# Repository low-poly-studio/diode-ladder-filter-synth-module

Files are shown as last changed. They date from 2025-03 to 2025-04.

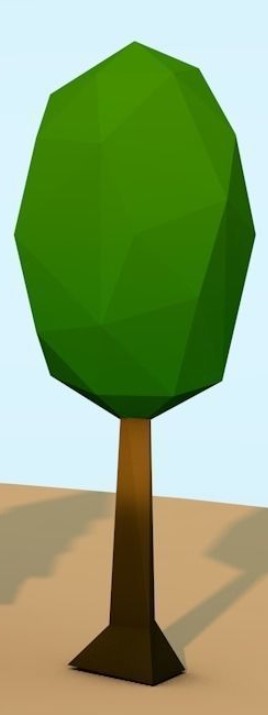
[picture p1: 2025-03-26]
artwork/low-poly-tree-4.jpg

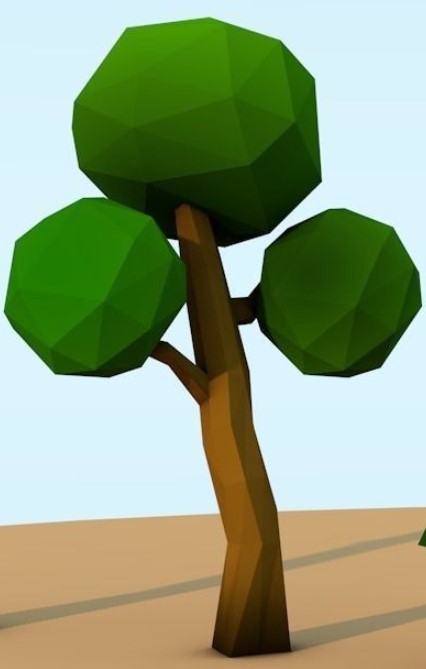
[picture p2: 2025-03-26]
artwork/low-poly-tree-3.jpg

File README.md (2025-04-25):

# diode-ladder-filter-synth-module
 Diode Ladder Filter Synth Module

 Putting this here as I dont have a better place for it at the moment

BL-HUF35A-AV-TRB - Red
TJ-S2012SW8TGLC0A-A5 - orange
BL-HJC36G-AV-TRB - amber
KT-0805Y - yellow, basic
KT-0805YG - yellow green
APT2012CGCK  - green
KT-0805G - emerald
LTST-C170TBKT - blue
E6C0805TKAY1UDA - foggy yellow lense ice blue
GZ2012D101TF - purple
XL-2012UPC - pink
KT-0805W - white

## JLC LED Library
| Colour 	| MF part 		 |  JLC part| Basic? |
|---		 |---			 |---		 |--- |
|red		 |BL-HUF35A-AV-TRB	|		 | |
|orange-red		|ORH-R35A	|	C205444	||
|Orange		|TJ-S2012SW8TGLC0A-A5	|		||
|Amber		|BL-HJC36G-AV-TRB	|	0605!	||
|Yellow		|KT-0805Y		||
|yellow-green	|KT-0805YG	|	|		|
|green		|APT2012CGCK		|	||
|emerald	|KT-0805G		||
|blue		|LTST-C170TBKT	|	|	|
|ice-blue	|E6C0805TKAY1UDA	||		|
|purple		|GZ2012D101TF		|	||
|pink		|XL-2012UPC		|		|	|
|white		|KT-0805W		|	||

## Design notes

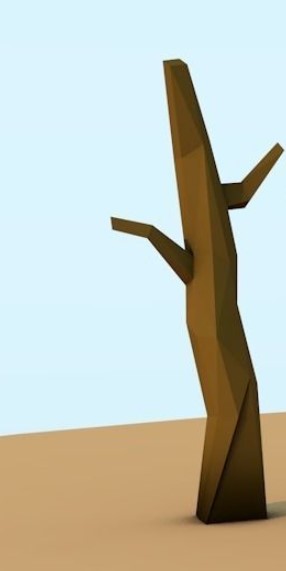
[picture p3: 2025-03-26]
artwork/low-poly-tree-2.jpg

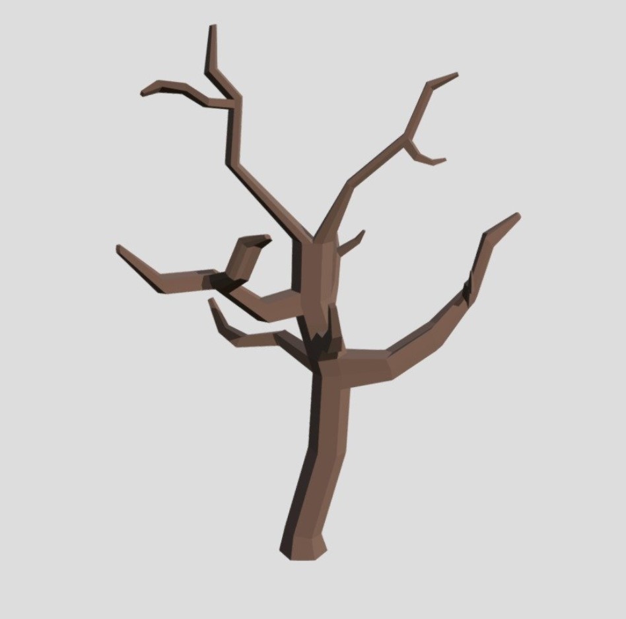
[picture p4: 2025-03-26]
artwork/low-poly-tree.jpg

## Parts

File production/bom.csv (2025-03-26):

Designator | Footprint | Quantity | Value | LCSC Part #
C1, C2, C3, C4, C5, C6, C7 | C_0805_2012_HandSolder_kawaii | 7 | 100n
C10, C11, C12, C13, C14 | 0805 | 5 | 1n
C8 | C_0805_2012_HandSolder_kawaii | 1 | 100p
C9 | 0805 | 1 | 1u
D1 | LED_0805_2012_Kawaii | 1 | V+
D10, D11, D12, D13, D14, D15, D7, D8, D9 | D_MiniMELF_kawaii | 9 | 1N4148
D16, D17 | LED_0805_2012_Kawaii | 2 | cv2
D2 | LED_0805_2012_Kawaii | 1 | V-
D3, D5 | LED_0805_2012_Kawaii | 2 | Audio Out
D4, D6 | LED_0805_2012_Kawaii | 2 | cv1
FB1, FB2 | 0805 | 2 | FerriteBead
J1 | synth-power-termbox-MPT-0,5-4-2.54_1x04_P2.54mm | 1 | power
J6 | synth-signal-MPT-1x10_P2.54mm_Horizontal_1 | 1 | synth-signal-header-10way
M1 | credit-card-screws | 1 | imogen-wren-card
PT1, PT2, PT3, PT4 | Potentiometer_Alpha-reversable | 4 | 100k
PT6, PT7 | Potentiometer_Bourns-reversable-1 | 2 | 100k-trim
R1, R2, R21, R24, R26, R27, R3, R4 | 0805 | 8 | 1k
R10 | 0805 | 1 | 2k
R11, R15, R23, R25, R5 | 0805 | 5 | 100k
R12 | 0805 | 1 | 14k
R13, R14 | 0805 | 2 | 68k
R16, R6 | 0805 | 2 | 27k
R17, R18, R19, R20, R22, R7, R8, R9 | 0805 | 8 | 33k
U1, U2 | SOIC-14_3.9x8.7mm_P1.27mm | 2 | TL074

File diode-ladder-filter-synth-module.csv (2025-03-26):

Id | Designator | Footprint | Quantity | Designation | Supplier and ref
1 | D14,D13,D15,D8,D10,D12,D7,D11,D9 | D_MiniMELF_kawaii | 9 | 1N4148
2 | R16,R6 | R_0805_2012Metric_Pad1.20x1.40mm_HandSolder | 2 | 27k
3 | C2,C4,C3,C1,C7,C5,C6 | C_0805_2012_HandSolder_kawaii | 7 | 100n
4 | D5,D3 | LED_0805_2012_Kawaii | 2 | Audio Out
5 | U2 | SOIC-14_3.9x8.7mm_P1.27mm | 1 | TL074
6 | R22,R7,R9,R19,R20,R18,R17,R8 | R_0805_2012Metric_Pad1.20x1.40mm_HandSolder | 8 | 33k
7 | J6 | synth-signal-MPT-1x10_P2.54mm_Horizontal_1 | 1 | synth-signal-header-10way
8 | PT1,PT3,PT4,PT2 | Potentiometer_Alpha-reversable | 4 | 100k
9 | C13,C14,C10,C11,C12 | C_0805_2012Metric_Pad1.18x1.45mm_HandSolder | 5 | 1n
10 | R26,R3,R1,R27,R4,R24,R21,R2 | R_0805_2012Metric_Pad1.20x1.40mm_HandSolder | 8 | 1k
11 | R23,R11,R15,R25,R5 | R_0805_2012Metric_Pad1.20x1.40mm_HandSolder | 5 | 100k
12 | D6,D4 | LED_0805_2012_Kawaii | 2 | cv1
13 | D2 | LED_0805_2012_Kawaii | 1 | V-
14 | C8 | C_0805_2012_HandSolder_kawaii | 1 | 100p
15 | R10 | R_0805_2012Metric_Pad1.20x1.40mm_HandSolder | 1 | 2k
16 | M1 | credit-card-screws | 1 | imogen-wren-card
17 | R13,R14 | R_0805_2012Metric_Pad1.20x1.40mm_HandSolder | 2 | 68k
18 | R12 | R_0805_2012Metric_Pad1.20x1.40mm_HandSolder | 1 | 14k
19 | J1 | synth-power-termbox-MPT-0,5-4-2.54_1x04_P2.54mm | 1 | power
20 | D17,D16 | LED_0805_2012_Kawaii | 2 | cv2
21 | PT7,PT6 | Potentiometer_Bourns-reversable-1 | 2 | 100k-trim
22 | FB1,FB2 | L_0805_2012Metric_Pad1.05x1.20mm_HandSolder | 2 | FerriteBead
23 | D1 | LED_0805_2012_Kawaii | 1 | V+
24 | U1 | SOIC-14_3.9x8.7mm_P1.27mm | 1 | TL074
25 | C9 | C_0805_2012Metric_Pad1.18x1.45mm_HandSolder | 1 | 1u

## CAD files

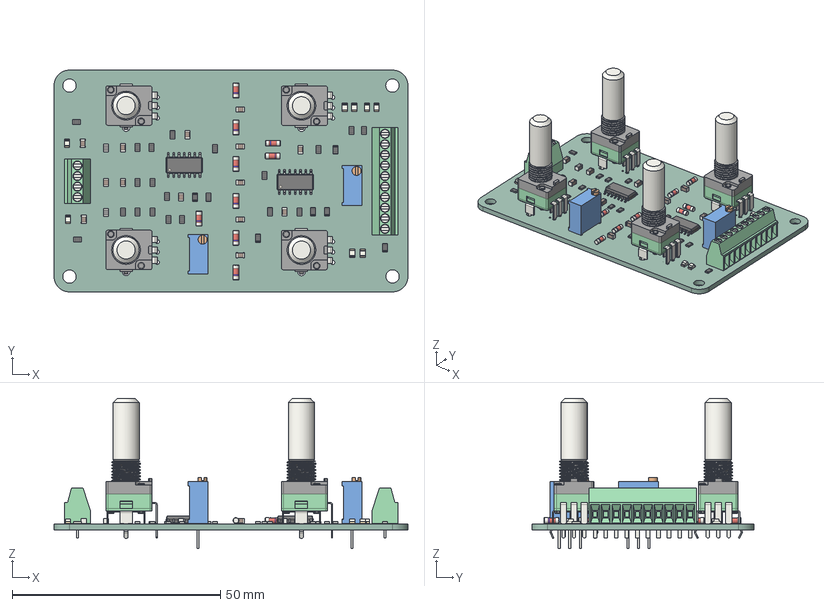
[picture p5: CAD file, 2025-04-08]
diode-ladder-filter-synth-module.step
85.1 x 53.3 x 36.1 mm
D_MiniMELF x 9
R_0805_2012Metric x 27
C_0805_2012Metric x 14
LED_0805_2012Metric x 8
SOIC-14_3.9x8.7mm_P1.27mm x 2
TerminalBlock_Phoenix_MPT-0,5-10-2.54_1x10_P2.54mm_Horizontal
ALPHA-RD901F-40 x 4
TerminalBlock_Phoenix_MPT-0,5-4-2.54_1x04_P2.54mm_Horizontal
Potentiometer_Bourns_3296W_Vertical x 2
L_0805_2012Metric x 2
diode-ladder-filter-synth-module_PCB

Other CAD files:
diode-ladder-filter-synth-module-CAD/ALPHA-RD901F-40.ipt
diode-ladder-filter-synth-module-CAD/C_0805_2012Metric.ipt
diode-ladder-filter-synth-module-CAD/D_MiniMELF.ipt
diode-ladder-filter-synth-module-CAD/LED_0805_2012Metric.ipt
diode-ladder-filter-synth-module-CAD/L_0805_2012Metric.ipt
diode-ladder-filter-synth-module-CAD/Potentiometer_Bourns_3296W_Vertical.ipt
diode-ladder-filter-synth-module-CAD/R_0805_2012Metric.ipt
diode-ladder-filter-synth-module-CAD/SOIC-14_3.9x8.7mm_P1.27mm.ipt
diode-ladder-filter-synth-module-CAD/TerminalBlock_Phoenix_MPT-0,5-10-2.54_1x10_P2.54mm_Horizontal.ipt
diode-ladder-filter-synth-module-CAD/TerminalBlock_Phoenix_MPT-0,5-4-2.54_1x04_P2.54mm_Horizontal.ipt
diode-ladder-filter-synth-module-CAD/diode-ladder-filter-synth-module.iam
diode-ladder-filter-synth-module-CAD/diode-ladder-filter-synth-module_PCB.ipt

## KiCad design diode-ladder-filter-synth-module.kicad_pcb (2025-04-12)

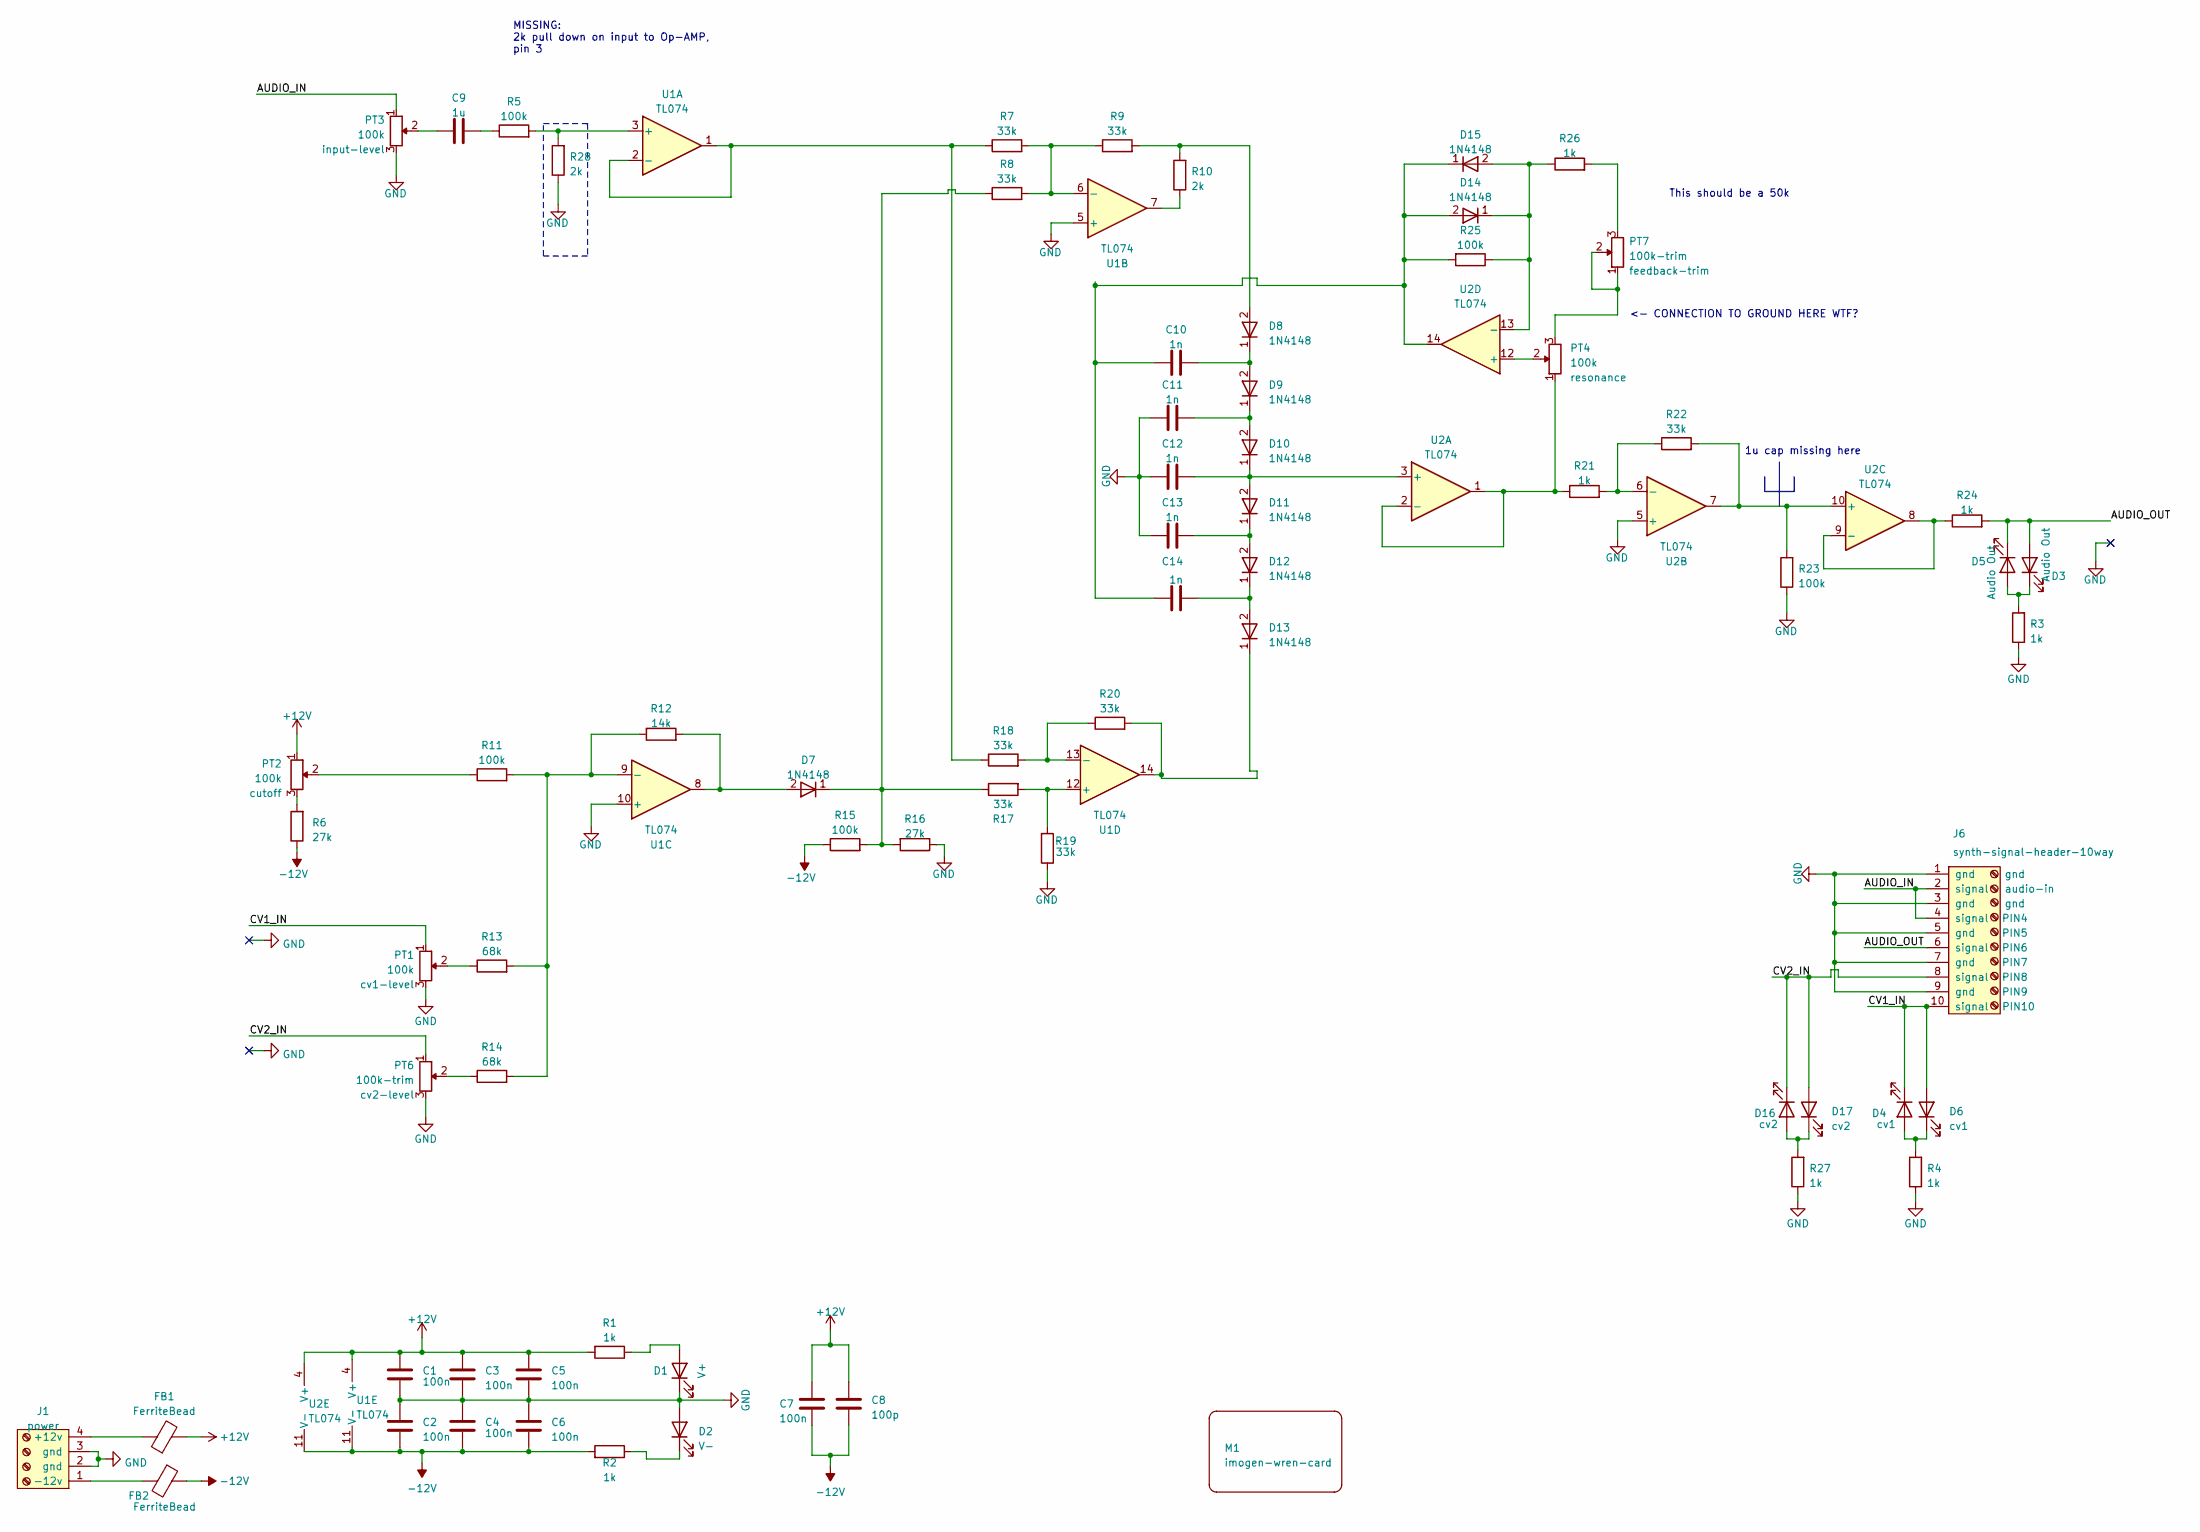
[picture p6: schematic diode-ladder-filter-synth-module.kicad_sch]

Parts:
C1, C2, C3, C4, C5, C6, C7: 100n; C_0805_2012_HandSolder_kawaii; JLCpart C779975
C8: 100p; C_0805_2012_HandSolder_kawaii; JLCpart C779975
C9: 1u; C_0805_2012Metric_Pad1.18x1.45mm_HandSolder
C10, C11, C12, C13, C14: 1n; C_0805_2012Metric_Pad1.18x1.45mm_HandSolder
D1: V+; LED_0805_2012_Kawaii; JLCpart C84259
D2: V-; LED_0805_2012_Kawaii; JLCpart C84259
D3, D5: Audio Out; LED_0805_2012_Kawaii; JLCpart C84259
D4, D6: cv1; LED_0805_2012_Kawaii; JLCpart C84259
D7, D8, D9, D10, D11, D12, D13, D14, D15: 1N4148; D_MiniMELF_kawaii
D16, D17: cv2; LED_0805_2012_Kawaii; JLCpart C84259
FB1, FB2: FerriteBead; L_0805_2012Metric_Pad1.05x1.20mm_HandSolder; JLCpart C845115
J1: power; synth-power-termbox-MPT-0,5-4-2.54_1x04_P2.54mm
J6: synth-signal-header-10way; synth-signal-MPT-1x10_P2.54mm_Horizontal_1
M1: imogen-wren-card; credit-card-screws
PT1, PT2, PT3, PT4: 100k; Potentiometer_Alpha-reversable
PT6, PT7: 100k-trim; Potentiometer_Bourns-reversable-1; JLCpart C118911
R1, R2, R3, R4, R21, R24, R26, R27: 1k; R_0805_2012Metric_Pad1.20x1.40mm_HandSolder; JLCpart C218388
R5, R11, R15, R23, R25: 100k; R_0805_2012Metric_Pad1.20x1.40mm_HandSolder; JLCpart C280020
R6, R16: 27k; R_0805_2012Metric_Pad1.20x1.40mm_HandSolder
R7, R8, R9, R17, R18, R19, R20, R22: 33k; R_0805_2012Metric_Pad1.20x1.40mm_HandSolder
R10, R28: 2k; R_0805_2012Metric_Pad1.20x1.40mm_HandSolder
R12: 14k; R_0805_2012Metric_Pad1.20x1.40mm_HandSolder
R13, R14: 68k; R_0805_2012Metric_Pad1.20x1.40mm_HandSolder
U1, U2: TL074; SOIC-14_3.9x8.7mm_P1.27mm

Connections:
+12V: C1.1, C3.1, C5.1, C7.1, C8.2, FB1.2, PT2.1, R1.2, U1.4 (V+), U2.4 (V+)
-12V: C2.2, C4.2, C6.2, C7.2, C8.1, FB2.1, R2.2, R6.1, R15.1, U1.11 (V-), U2.11 (V-)
/AUDIO_IN: J6.2 (signal), J6.4 (signal), PT3.1
/AUDIO_OUT: D3.2 (A), D5.1 (K), J6.6 (signal), R24.2
/CV1_IN: D4.1 (K), D6.2 (A), J6.10 (signal), PT1.1
/CV2_IN: D16.1 (K), D17.2 (A), J6.8 (signal), PT6.1
GND: C1.2, C2.1, C3.2, C4.1, C5.2, C6.1, C11.1, C12.1, C13.1, D1.1 (K), D2.2 (A), J1.2 (gnd), J1.3 (gnd), J6.1 (gnd), J6.3 (gnd), J6.5 (gnd), J6.7 (gnd), J6.9 (gnd), PT1.3, PT3.3, PT6.3, R3.1, R4.1, R16.1, R19.1, R23.1, R27.1, U1.5 (+), U1.10 (+), U2.5 (+)
unnamed: C9.1, PT3.2
unnamed: C9.2, R5.1
unnamed: D1.2 (A), R1.1
unnamed: D2.1 (K), R2.1
unnamed: D3.1 (K), D5.2 (A), R3.2
unnamed: D4.2 (A), D6.1 (K), R4.2
unnamed: D7.2 (A), R12.2, U1.8
unnamed: D7.1 (K), R8.1, R15.2, R16.2, R17.1
unnamed: D8.2 (A), R9.2, R10.2
unnamed: C10.2, D8.1 (K), D9.2 (A)
unnamed: C11.2, D9.1 (K), D10.2 (A)
unnamed: C12.2, D10.1 (K), D11.2 (A), U2.3 (+)
unnamed: C13.2, D11.1 (K), D12.2 (A)
unnamed: C14.2, D12.1 (K), D13.2 (A)
unnamed: D13.1 (K), R20.2, U1.14
unnamed: C10.1, C14.1, D14.2 (A), D15.1 (K), R25.2, U2.14
unnamed: D14.1 (K), D15.2 (A), R25.1, R26.1, U2.13 (-)
unnamed: D16.2 (A), D17.1 (K), R27.2
unnamed: FB1.1, J1.4 (+12v)
unnamed: FB2.2, J1.1 (-12v)
unnamed: PT1.2, R13.1
unnamed: PT2.2, R11.1
unnamed: PT2.3, R6.2
unnamed: PT4.3, PT7.1, PT7.2
unnamed: PT6.2, R14.1
unnamed: PT7.3, R26.2
unnamed: R10.1, U1.7
unnamed: R5.2, U1.3 (+)
unnamed: R7.1, R18.1, U1.1, U1.2 (-)
unnamed: R7.2, R8.2, R9.1, U1.6 (-)
unnamed: R11.2, R12.1, R13.2, R14.2, U1.9 (-)
unnamed: R17.2, R19.2, U1.12 (+)
unnamed: R18.2, R20.1, U1.13 (-)
unnamed: PT4.1, R21.1, U2.1, U2.2 (-)
unnamed: R21.2, R22.1, U2.6 (-)
unnamed: R22.2, R23.2, U2.7, U2.10 (+)
unnamed: R24.1, U2.8, U2.9 (-)
unnamed: PT4.2, U2.12 (+)

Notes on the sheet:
This should be a 50k
<- CONNECTION TO GROUND HERE WTF?
1u cap missing here
MISSING: 2k pull down on input to Op-AMP, pin 3

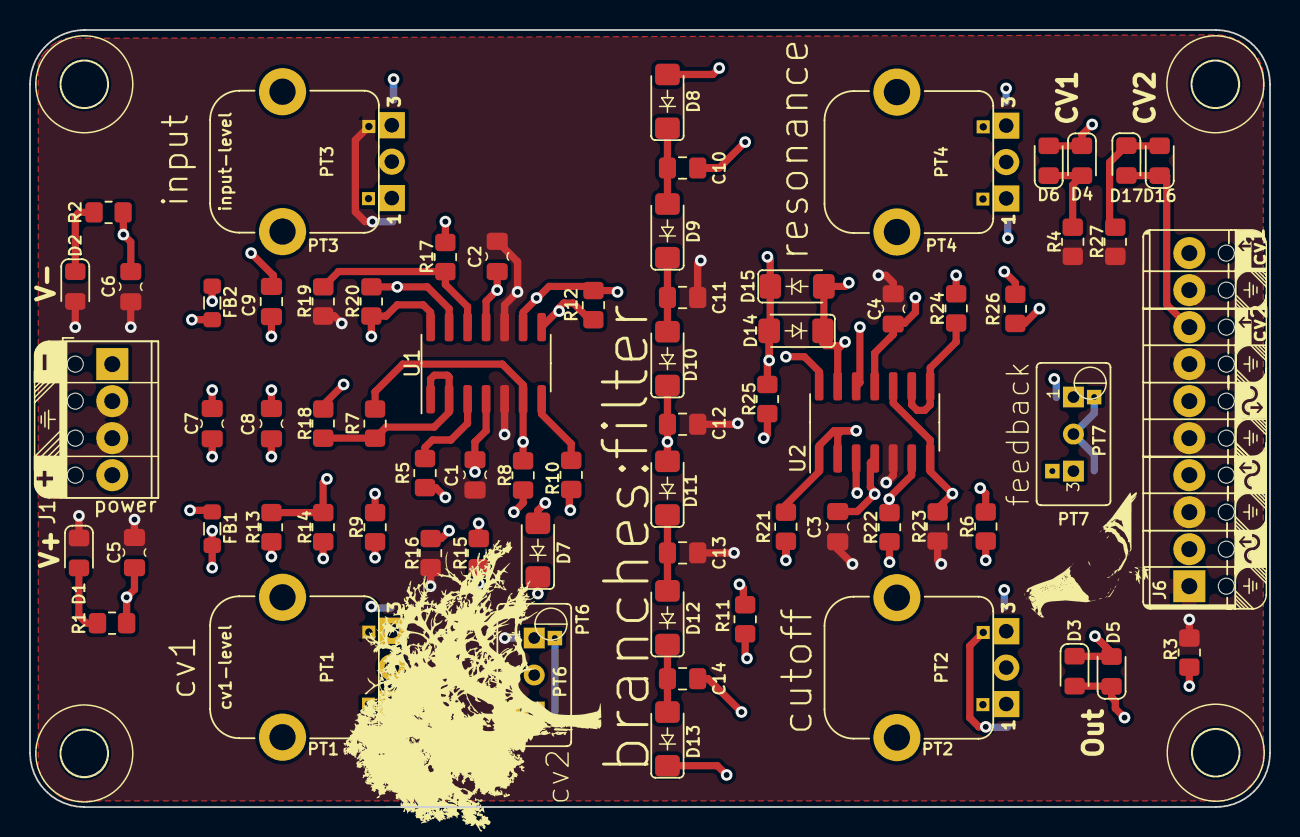
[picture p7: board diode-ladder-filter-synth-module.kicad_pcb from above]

Board: 4 copper layers, 85.1 x 53.3 mm, 71 parts (0 on the bottom side), 45 nets.

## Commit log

2025-03-26 finished design & added fabrication outputs
    [bom.csv, designators.csv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]
2025-03-27 added JLC LED part nos.
2025-04-08 added steps n stuff
    [ALPHA-RD901F-40.ipt, C_0805_2012Metric.ipt, D_MiniMELF.ipt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]
2025-04-11 found errors against schematic. Retry tonight
    [diode-ladder-filter-synth-module.kicad_pcb, diode-ladder-filter-synth-module.kicad_sch]
